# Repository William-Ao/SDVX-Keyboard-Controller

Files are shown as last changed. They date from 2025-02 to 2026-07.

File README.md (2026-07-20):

# PSA: I probably would not do anything in this repo, I have since learned a lot about making these things. Maybe I'll make a new one, not sure.

# SDVX Full Size Controller - Keyboard Style v0.1
A full size controller for Sound Voltex with custom arcade size keycaps, and no _required_ soldering (technically).

I wanted it to be as easy to put together as possible, so the case is made of small, repeatable parts that _should_ be capable of being printed on most printers without any extra hassle of splicing.

# Note: I'm putting this on the backburner until I get my 3D printer, I can make this way better and I think I'm kind of stupid for trying to split it up how I did. Also, PCB's are overrated


###### _Figure 1. v0.1 Full assembly_


###### _Figure 2. v0.2 Modular version_

## Table of Contents:
 [Tools Required](#tools-required)
 
 [Parts Needed](#parts-needed)
 
 [General Instructions](#general-instructions)
 
 [PCB Ordering](#pcb-ordering)
 
 [3D Printing](#3d-printing)
 
 [Todo](#todo)
 
 [Known Issues](#known-issues)
 
 [Part/Assembly Photos](#partassembly-photos)

## Tools Required:
- Gorilla Glue (If 3D printing the case in many parts, which is the most likely scenario)
- Screwdriver to attach encoders
- Allen Key (Check if the knob you buy comes with an appropriately sized one)

## Parts Needed:
- 1x Arduino Micro WITH Headers
- 6x Mechanical keyboard switch of your choice
- 20x Screw in PCB mount stabilizers (I used Durock V3 screw ins)
- 8x 3u Stabilizer wires
- 2x 2u Stabilizer wires
- 6x Kailh Hotswap sockets (Technically optional?)
- 1x PCB (They make you order 5 usually)
- 1x 3D Printed case

## General Instructions:
1. Order PCB [Instructions](#pcb-ordering)
2. 3D Print in many parts and assemble [Details](#3d-printing)
3. Solder Kailh hotswap sockets onto PCB (Technically optional if you just handwire the pins by stuffing the hole with some conductive material)
4. Screw in stabilizers and clip in wires
5. Apply gasket strips to edge of PCB (place them so they're half on/half off the pcb)
6. Screw encoders into their respective housing
7. Place O-rings or felt on encoder shaft
8. Put knob on encoder and tighten
9. Wire encoder, matching your vendor's datasheet with the info printed on the PCB (TODO)
10. Plug Arduino Micro into your computer and upload the Firmware
11. Put keycaps on
12. Socket Arduino into PCB (Optional: Secure it with tape or something)
13. Fill bottom of 3D printed case with foam/dense material
14. Place PCB assembly into socket on the case
15. Game

## PCB Ordering
Make a ZIP archive out of the PCB folder and sent it to a PCB manufacturer of your choosing. Make sure it says 1.6mm, 2 layer. I personally used JLCPCB cause they were the cheapest for me (I'm in the US, also no this is not sponsored). Do some digging and find out what is cheapest for where you live, JLCPCB and PCBWAY seem to be good, Aisler for EU, etc.

The PCB is designed to just have an Arduino Micro (with headers) plug into the back, and just have screw in stabilizers, and (Technically optional?) Kailh hotswap sockets (I'm going to solder mine, I'll update if I try one handwired)

## 3D Printing
The keycap stems are the finest detail in the assembly, so a resin printer is highly recommended. Everything else it doesn't really matter.
(It is probably doable with a 0.2mm nozzle on a filament printer but you might have to mess with the hole sizing yourself.)

To print: After downloading and unzipping, go to SDVX-Keyboard-Controller/3D Manufacturing Files, you should see:
- bt_keycap.3mf
- fx_keycap.3mf
- stem_tolerance_tester.3mf

These are the BT and FX button keycaps, named respectively. I would recommend printing the stem tolerance tester first though to see what setting you need to print with to make the stems fit nicely on the switch. If you do end up needing to edit the tolerances, the design files are under the SDVX-Keyboard-Controller/3D Manufacturing Files/Design Files

The case is in the sdvx_case_v0.1 folder, split into many parts approx 52x52 mm. The files are named as follows:
- enc_L, enc_R are the actual encoder housings, the _side and _lower files go on the side and bottom
- The PCB coordinates start in the top left, you can probably piece it together afterwards with the picture but just know that the top left is 0_0 and the bottom right is 5_2

After printing all the individual parts (Make sure they fit as you put them together), glue them together with your choice of adhesive (e.g. Gorilla Glue)

## Todo
- Improve case by culling the extra parts of the baseplate and adding a connector between the encoder housing and the PCB housing that isn't the baseplate

## Known Issues
- Dunno yet

[Jump to top of page](#table-of-contents)

## Part/Assembly Photos

[Jump to top of page](#table-of-contents)

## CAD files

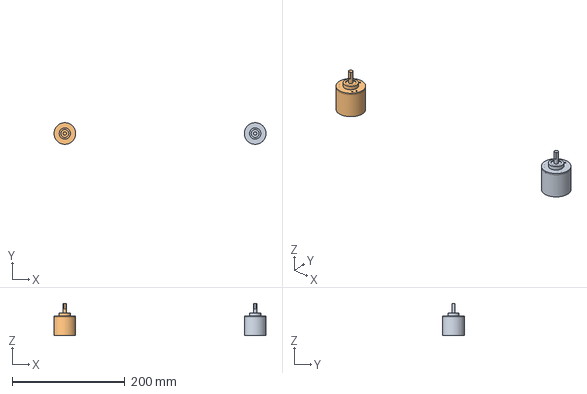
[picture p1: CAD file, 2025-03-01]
controller_v0.3/Assets/sdvx_modular_controller_assembly.FCStd
376.5 x 38.5 x 57.0 mm

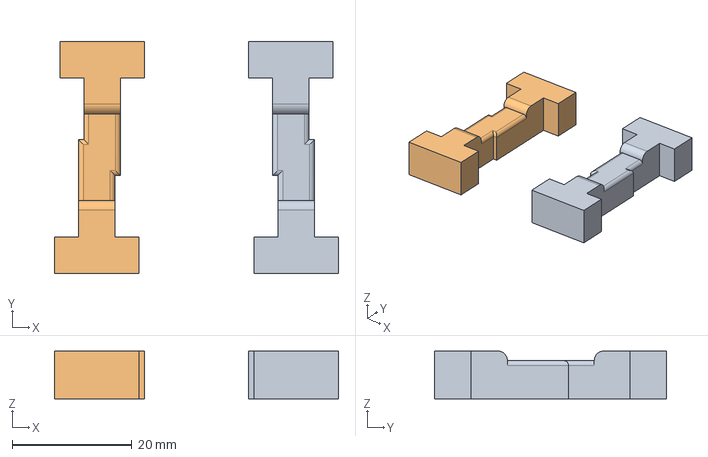
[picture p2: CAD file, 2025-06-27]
controller_v0.3/3D_Files/Designs/sdvx_FX_connector_bent_right.FCStd
47.4 x 38.7 x 8.00 mm
Body (Mirror #1)

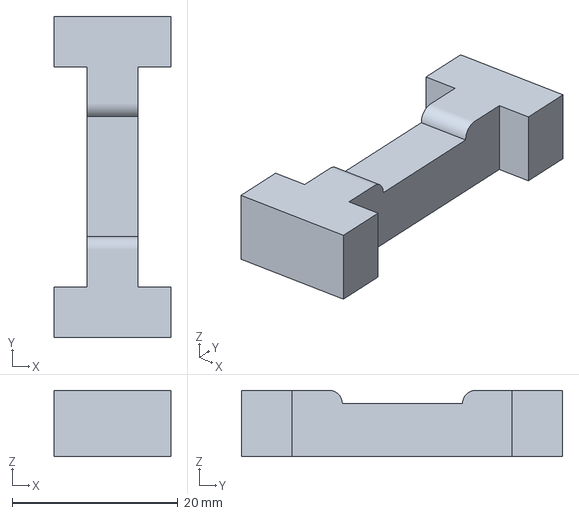
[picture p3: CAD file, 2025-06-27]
controller_v0.3/3D_Files/sdvx_FX_connector_straight.3mf
14.1 x 38.7 x 8.00 mm

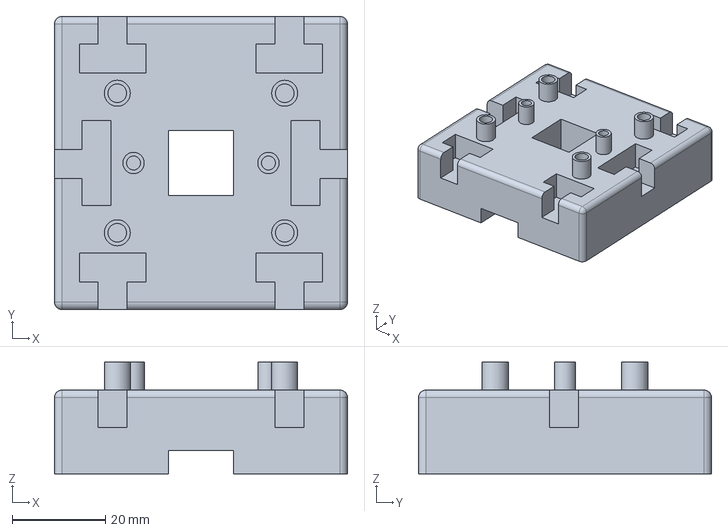
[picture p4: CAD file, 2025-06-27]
controller_v0.3/3D_Files/Designs/revised_sdvx_buttons_housing.FCStd
63.0 x 63.0 x 24.0 mm

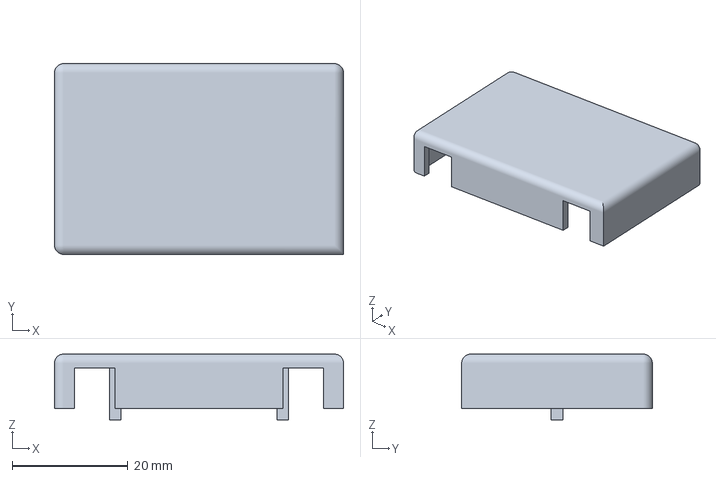
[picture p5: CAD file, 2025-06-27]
controller_v0.3/3D_Files/fx_keycap.3mf
50.0 x 33.0 x 11.4 mm

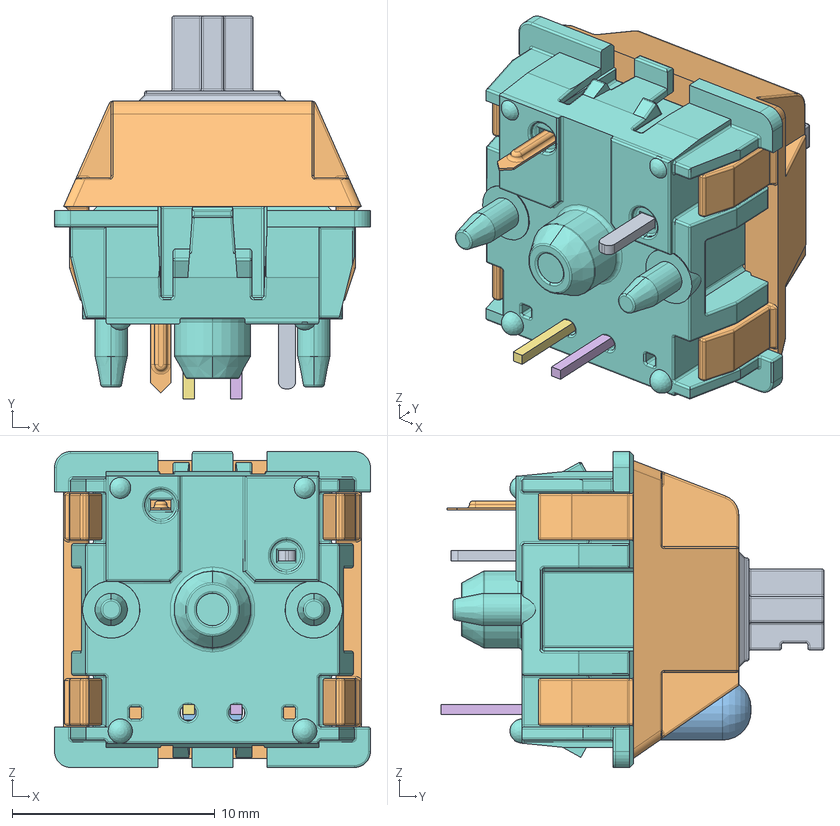
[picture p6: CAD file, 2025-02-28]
controller_v0.3/Assets/cherry_switch.FCStd
15.6 x 18.9 x 15.6 mm
MX ÃÃ¡ Â°Â´Â¼Ã¼Â¡Ã¤_Â¨Â¹___Â¡Â§1
MX ÃÃ¡ ÃÃ¡ÃÃ¥Â¨Â¢Â¨Â¬_Â¡Â§Â¡Ã©Â¡Â§__
MXÃÃ¡ ÃÃÃÂ±LEDLEDLED
MXÃÃ¡ ÃÃÃÂ±LEDLEDLED001
MXÃÃ¡ ÃÃÃÂ±LEDLEDLED002
MXÃÃ¡ ÃÃÃÂ±LEDLEDLED003
MXÃÃ¡ ÃÃÃÂ±LEDLEDLED004
MXÃÃ¡ ÃÃ¡ÃÃ¥ ÂµÃÂ²Â¿ Â¦ÃÂ¡Ã2__ÃÂ¬ÃÃ_Â¨Â¢2____Â¨Â¨_
ÃÃ«Â½Ã ___ÃÂ¬ÃÃ__Â¨Â¨_
ÃÃ«Â½Ã ___ÃÂ¬ÃÃ__Â¨Â¨_001

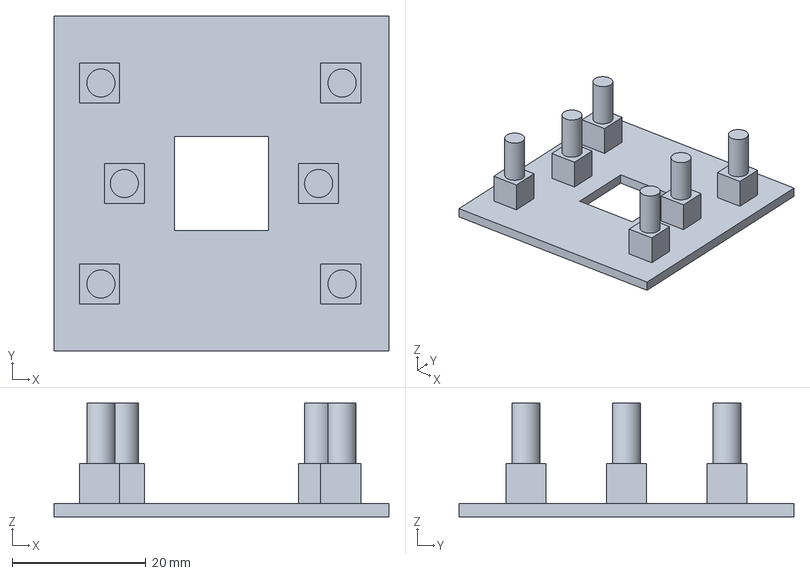
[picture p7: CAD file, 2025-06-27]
controller_v0.3/3D_Files/Designs/stabilizer_tolerance.FCStd
50.0 x 50.0 x 17.0 mm

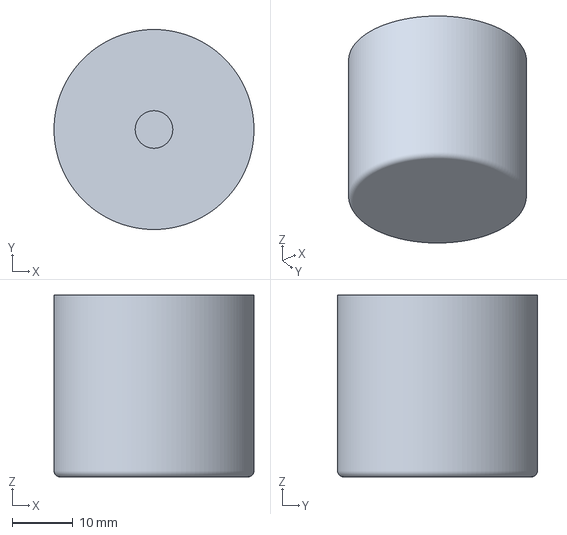
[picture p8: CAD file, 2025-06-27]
controller_v0.3/3D_Files/knob_mockup-BodyFillet.3mf
33.0 x 33.0 x 30.0 mm

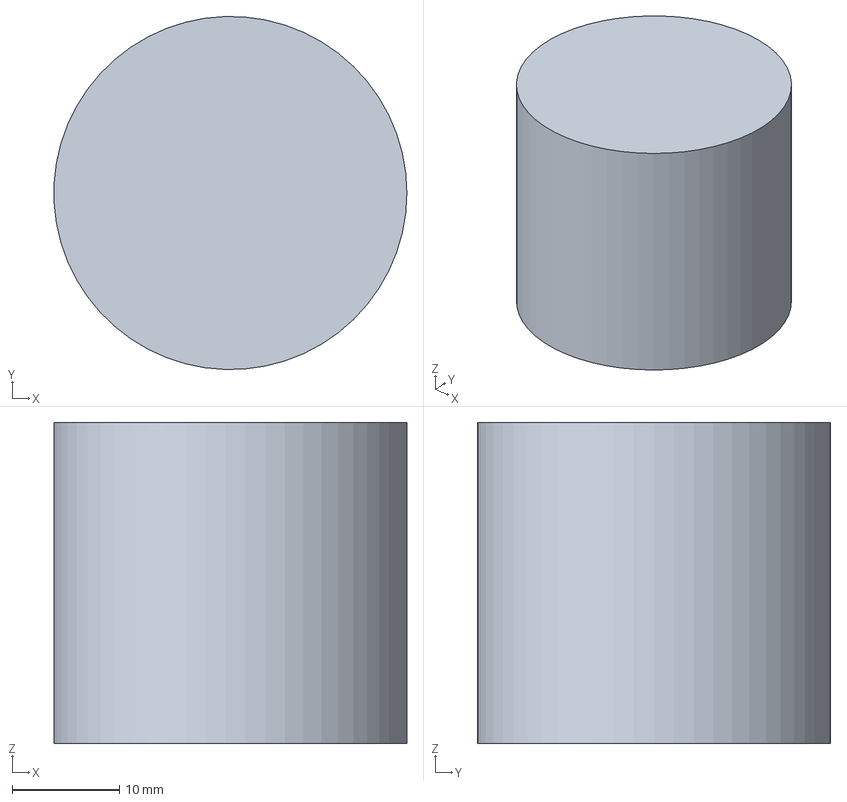
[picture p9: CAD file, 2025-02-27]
controller_v0.3/Assets/knob_mockup.FCStd
33.0 x 33.0 x 30.0 mm

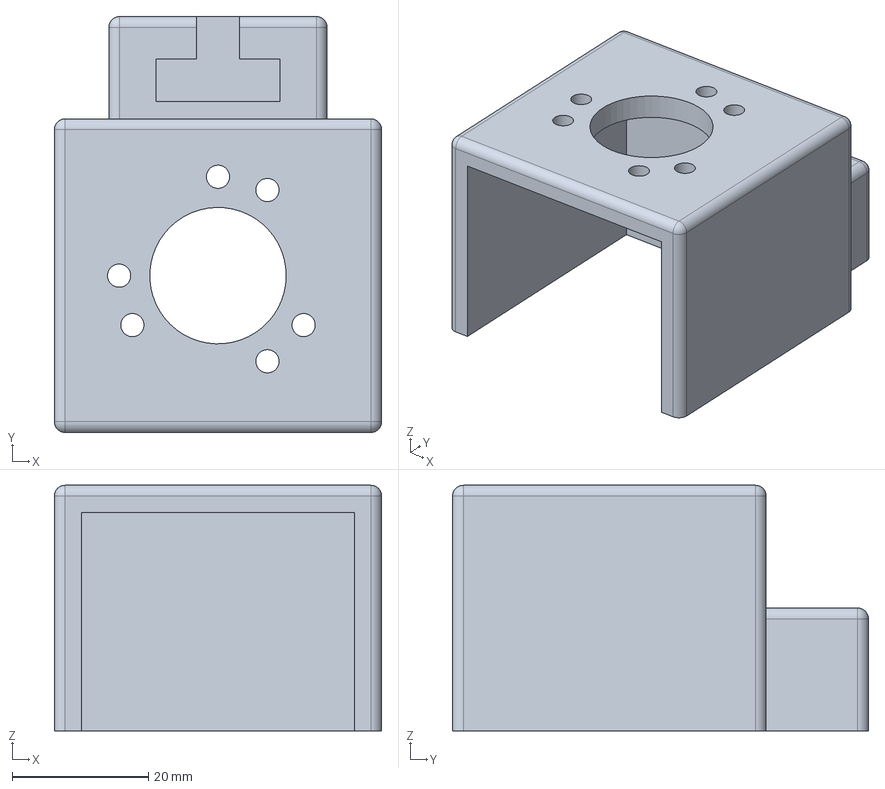
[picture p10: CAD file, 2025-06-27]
controller_v0.3/3D_Files/Designs/sdvx_encoder_housing.FCStd
48.0 x 61.0 x 36.0 mm

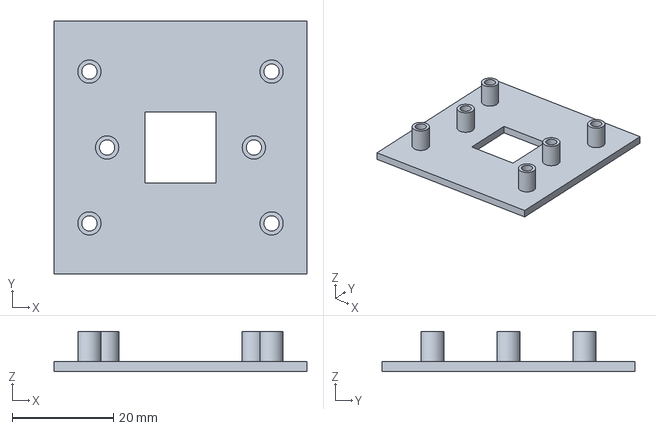
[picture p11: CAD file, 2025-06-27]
controller_v0.3/3D_Files/stabilizer_tolerance-BodyPocket001.3mf
50.0 x 50.0 x 8.00 mm

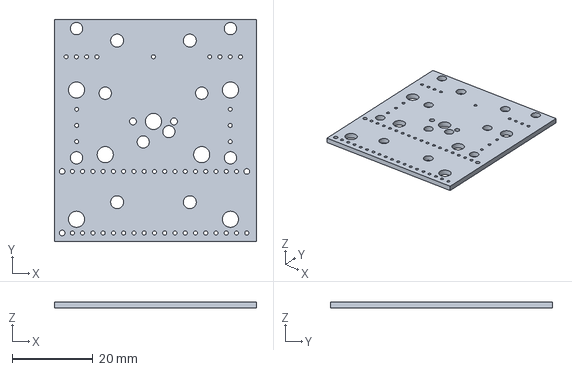
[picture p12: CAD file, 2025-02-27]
controller_v0.3/Assets/sdvx_modular_pcb.FCStd
50.0 x 55.0 x 1.60 mm

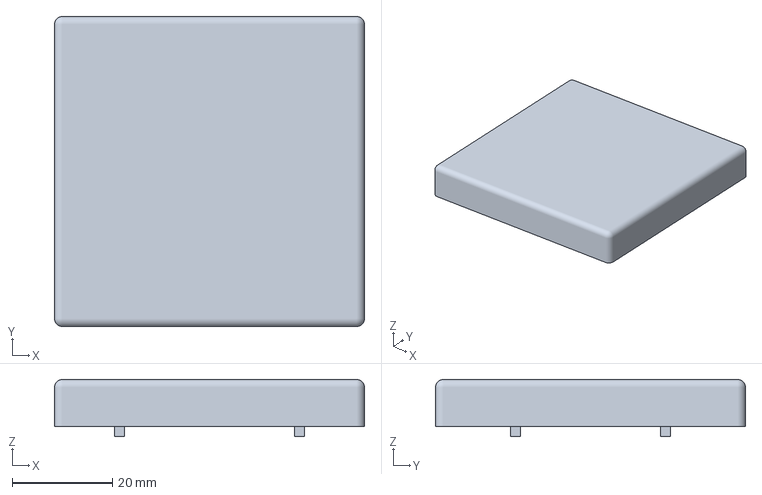
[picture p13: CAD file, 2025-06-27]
controller_v0.3/3D_Files/bt_keycap.3mf
62.0 x 62.0 x 11.4 mm

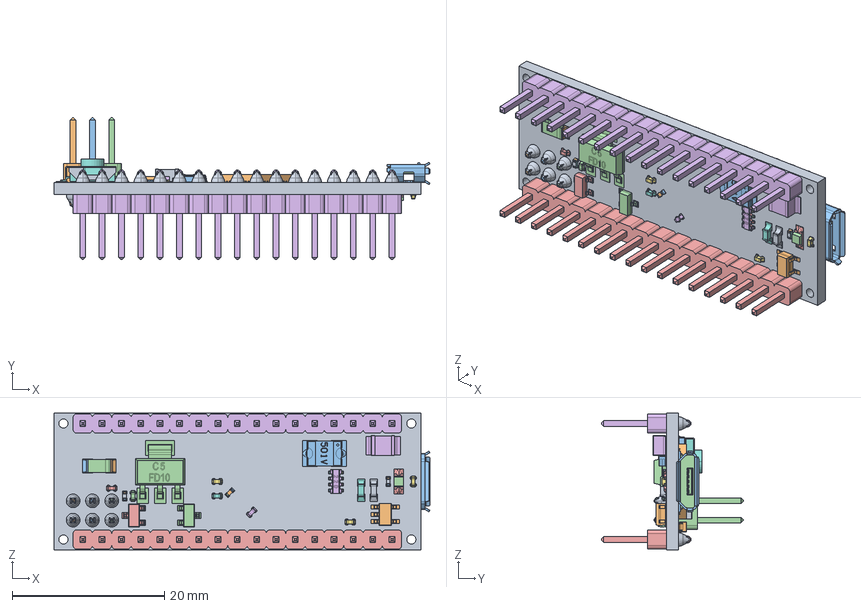
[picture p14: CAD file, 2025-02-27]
controller_v0.3/Assets/ArduinoMicro.FCStd
49.4 x 18.6 x 18.0 mm
arduino micro board
MICRO_2pin_header__02
MICRO_2pin_header__003
MICRO_2pin_header__004
MICRO_17pin_header__
MICRO_17pin_header__001
micro RESET CORE
micro RESET CORE001
micro RESET
atmega32U4
micro usb shell
micro usb internal
micro usb contact
micro usb contact001
micro usb contact002
micro usb contact003
micro usb contact004
MICRO_led2
MICRO_led003
MICRO_led005
MICRO_led006
MICRO_led008
MICRO_led009
MICRO_led011
MICRO_led012
micro_lmv358
micro mf-msmf050-2
MICRO - reg
MICRO_402 resistor
MICRO_402 resistor001
MICRO_402 resistor002
MICRO_402 resistor003
MICRO_402 resistor005
MICRO_402 resistor006
MICRO_402 resistor007
MICRO_402 resistor008
MICRO_402 resistor010
MICRO_402 resistor011
MICRO_402 resistor012
MICRO_402 resistor013
MICRO_402 resistor015
MICRO_402 resistor016
MICRO_402 resistor017
MICRO_402 resistor018
MICRO_402 resistor020
MICRO_402 resistor021
MICRO_402 resistor022
MICRO_402 resistor023
micro solid tantalum cap 22u
MH2029-300Y
micro_crystal 3.2 x 2.5
c0402
c0403
c0404
c0405
MICRO_402 resistor025
MICRO_402 resistor026
MICRO_402 resistor027
MICRO_402 resistor028
c0406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

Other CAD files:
controller_v0.3/3D_Files/Designs/bt_keycap.FCStd
controller_v0.3/3D_Files/Designs/sdvx_FX_connector_straight.FCStd
controller_v0.3/3D_Files/sdvx_encoder_housing.3mf
controller_v0.3/3D_Files/Designs/sdvx_encoder_connector.FCStd
controller_v0.1/3D Manufacturing Files/Design Files/bt_keycap_nolip.FCStd
controller_v0.1/3D Manufacturing Files/Design Files/sdvx_case_baseplate.FCStd
controller_v0.1/3D Manufacturing Files/Design Files/sdvx_case_baseplate_splitting.FCStd
controller_v0.1/3D Manufacturing Files/bt_keycap.3mf
controller_v0.1/3D Manufacturing Files/bt_keycap_nolip.3mf
controller_v0.1/3D Manufacturing Files/fx_keycap.3mf
controller_v0.1/3D Manufacturing Files/sdvx_case_v0.1/sdvx_case_v0.1_raw.3mf
controller_v0.1/3D Manufacturing Files/sdvx_case_v0.1/sdvx_case_v0.1_split/sdvx_case_enc_L.3mf
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

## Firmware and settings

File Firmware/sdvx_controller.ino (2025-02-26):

/*Arduino SDVX Controller Code for Leonardo
 * 2 Encoders + 10 Buttons
 * Based on original code from:
 * http://knuckleslee.blogspot.com/2018/06/RhythmCodes.html
 * 
 * Arduino Joystick Library
 * https://github.com/MHeironimus/ArduinoJoystickLibrary/
 */
#include <Joystick.h>
Joystick_ Joystick(JOYSTICK_DEFAULT_REPORT_ID,JOYSTICK_TYPE_GAMEPAD, 10, 0,
 true, true, false, false, false, false, false, false, false, false, false);

boolean state[2]={false}, set[4]={false};
int encL=0, encR=0;
const int PULSE = 360;  //number of pulses per revolution of encoders 
byte EncPins[]    = {18, 19, 20, 21};
byte ButtonPins[] = {5, 6, 7, 8, 9, 10};

/* pin assignments
 * VOL-L Green to pin 0 and White to pin 1
 * VOL-R Green to pin 2 and White to pin 3
 * ButtonPins {5,7,9,11,13,19,21,23,15,17} = Button input 1 to 10
 *    connect button pin to ground to trigger button press
 */
 
byte ButtonCount = sizeof(ButtonPins) / sizeof(ButtonPins[0]);
byte EncPinCount = sizeof(EncPins) / sizeof(EncPins[0]);

int ReportDelay = 700;
unsigned long ReportRate;

void setup() {
  Serial.begin(9600);
  Joystick.begin(false);
  Joystick.setXAxisRange(-PULSE/2, PULSE/2-1);
  Joystick.setYAxisRange(-PULSE/2, PULSE/2-1);
  
  // setup I/O for pins
  for(int i=0; i<ButtonCount; i++) {
    pinMode(ButtonPins[i], INPUT_PULLUP);
  }
  for(int i=0; i<EncPinCount; i++) {
    pinMode(EncPins[i], INPUT_PULLUP);
  }

  //setup interrupts
  attachInterrupt(digitalPinToInterrupt(EncPins[0]), doEncoder0, CHANGE);
  attachInterrupt(digitalPinToInterrupt(EncPins[2]), doEncoder1, CHANGE);
} //end setup

void loop() {
  ReportRate = micros();
  
  // read buttons
  for(int i=0; i<ButtonCount; i++) {
    Joystick.setButton(i, !(digitalRead(ButtonPins[i])));
  }

  //read encoders, detect overflow and rollover
  if(encL < -PULSE/2 || encL > PULSE/2-1)
    encL = constrain(encL*-1, -PULSE/2, PULSE/2-1);
  if(encR < -PULSE/2 || encR > PULSE/2-1)
    encR = constrain(encR*-1, -PULSE/2, PULSE/2-1);
  Joystick.setXAxis(encL);
  Joystick.setYAxis(encR);

  //report
  Joystick.sendState();
  delayMicroseconds(ReportDelay);
  //ReportRate Display
  Serial.print(micros() - ReportRate);
  Serial.println(" micro sec per loop");
}//end loop

//Interrupts
void doEncoder0() {
  if(state[0] == false && digitalRead(EncPins[0]) == LOW) {
    set[0] = digitalRead(EncPins[1]);
    state[0] = true;
  }
  if(state[0] == true && digitalRead(EncPins[0]) == HIGH) {
    set[1] = !digitalRead(EncPins[1]);
    if(set[0] == true && set[1] == true) {
      encL++;
    }
    if(set[0] == false && set[1] == false) {
      encL--;
    }
    state[0] = false;
  }
}

void doEncoder1() {
  if(state[1] == false && digitalRead(EncPins[2]) == LOW) {
    set[2] = digitalRead(EncPins[3]);
    state[1] = true;
  }
  if(state[1] == true && digitalRead(EncPins[2]) == HIGH) {
    set[3] = !digitalRead(EncPins[3]);
    if(set[2] == true && set[3] == true) {
      encR++;
    }
    if(set[2] == false && set[3] == false) {
      encR--;
    }
    state[1] = false;
  }
}

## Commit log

2025-02-26 Controller v0.1
    First revision keycaps, case and PCB
    [bt_keycap.3mf, case.3mf, fx_keycap.3mf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]
2025-02-26 SDVX Case v0.1 Split Segments Added
    Split segments added ~52x52 mm tiles
    [sdvx_case_enc_L.3mf, sdvx_case_enc_L_lower.3mf, sdvx_case_enc_L_side.3mf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]
2025-02-26 PCB Updated + Firmware Push
    Fixed incorrect ground connection in PCB, technically still usable if you just hook it up to ground cause I won't have the pin initialized in the firmware.
    Speaking of, first firmware version, untested
    [keyboard-B_Cu.gbr, keyboard-B_Mask.gbr, keyboard-B_Paste.gbr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]
2025-02-26 Added Design Files
    Added FreeCad design files for all parts+ Stem tolerance tester
    [bt_keycap.FCStd, fx_keycap.FCStd, sdvx_case_baseplate.FCStd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]
2025-02-27 Added some assembly files
    [Sdvx_con_assembly.FCStd, bt_keycap.FCStd, fx_keycap.FCStd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]
2025-02-27 Added bt_keycap_nolip
    PCB is messed up in this iteration
    [Sdvx_con_assembly.FCStd, bt_keycap_nolip.3mf, bt_keycap_nolip.FCStd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]
2025-02-27 PCB v5 and BT Keycap Update
    bt_keycap.3mf updated for new PCB stabilizer hole spacing.
    [bt_keycap.3mf, bt_keycap.FCStd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]
2025-02-27 Edited assembly files
    [Sdvx_con_assembly.FCStd, pcb.FCStd, sdvx_case_baseplate.FCStd]
2025-02-27 Repo Reorg, Addition of v0.2
    [ArduinoMicro.FCStd, Sdvx_con_assembly.FCStd, bt_keycap.3mf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]
2025-02-27 Added Modular Full Assembly
    Also fixed error in encoder housing
    [bt_keycap.FCStd, fx_keycap.FCStd, knob_mockup.FCStd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]
2025-02-28 v0.3 Added
    Controller v0.3:
    - Removed stabilizers, added stems to keycaps and button housings
    - Assembly updated to include a keycap/switch
    - Updated PCB with through holes for new keycap design
    [ArduinoMicro.FCStd, bt_keycap.3mf, bt_keycap.FCStd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]
2025-02-28 Updated encoder housing
    - Added some space for tolerance (~0.125 on each side?)
    - Updated pcb/button housing spacing
    - Filled in button housing
    [bt_keycap.3mf, bt_keycap.FCStd, fx_keycap.3mf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]
2025-03-01 Updated tolerances on keycap stems
    [bt_keycap.3mf, bt_keycap.FCStd, fx_keycap.3mf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]
2025-03-01 Touched up parts to make them nice
    [bt_keycap.3mf, bt_keycap.FCStd, fx_keycap.3mf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]
2025-06-27 Updated clearances? I think, i forget its been a while
    [bt_keycap.3mf, bt_keycap.FCStd, fx_keycap.3mf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]
